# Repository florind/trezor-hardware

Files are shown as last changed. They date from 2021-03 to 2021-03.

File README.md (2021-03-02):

# Hardware design of Trezor

##
Using only 0603 components instead of 0402. Beware, the pushbuttons are also changed with https://www.mouser.de/ProductDetail/506-147873-2 (I have those).



https://trezor.io/

## Open Source Hardware

oshw

The content of this repo is dual licensed under the following licenses:
* [GNU Affero General Public License v3](COPYING)
* [CERN Open Hardware Licence Version 2 - Strongly Reciprocal](LICENSE)

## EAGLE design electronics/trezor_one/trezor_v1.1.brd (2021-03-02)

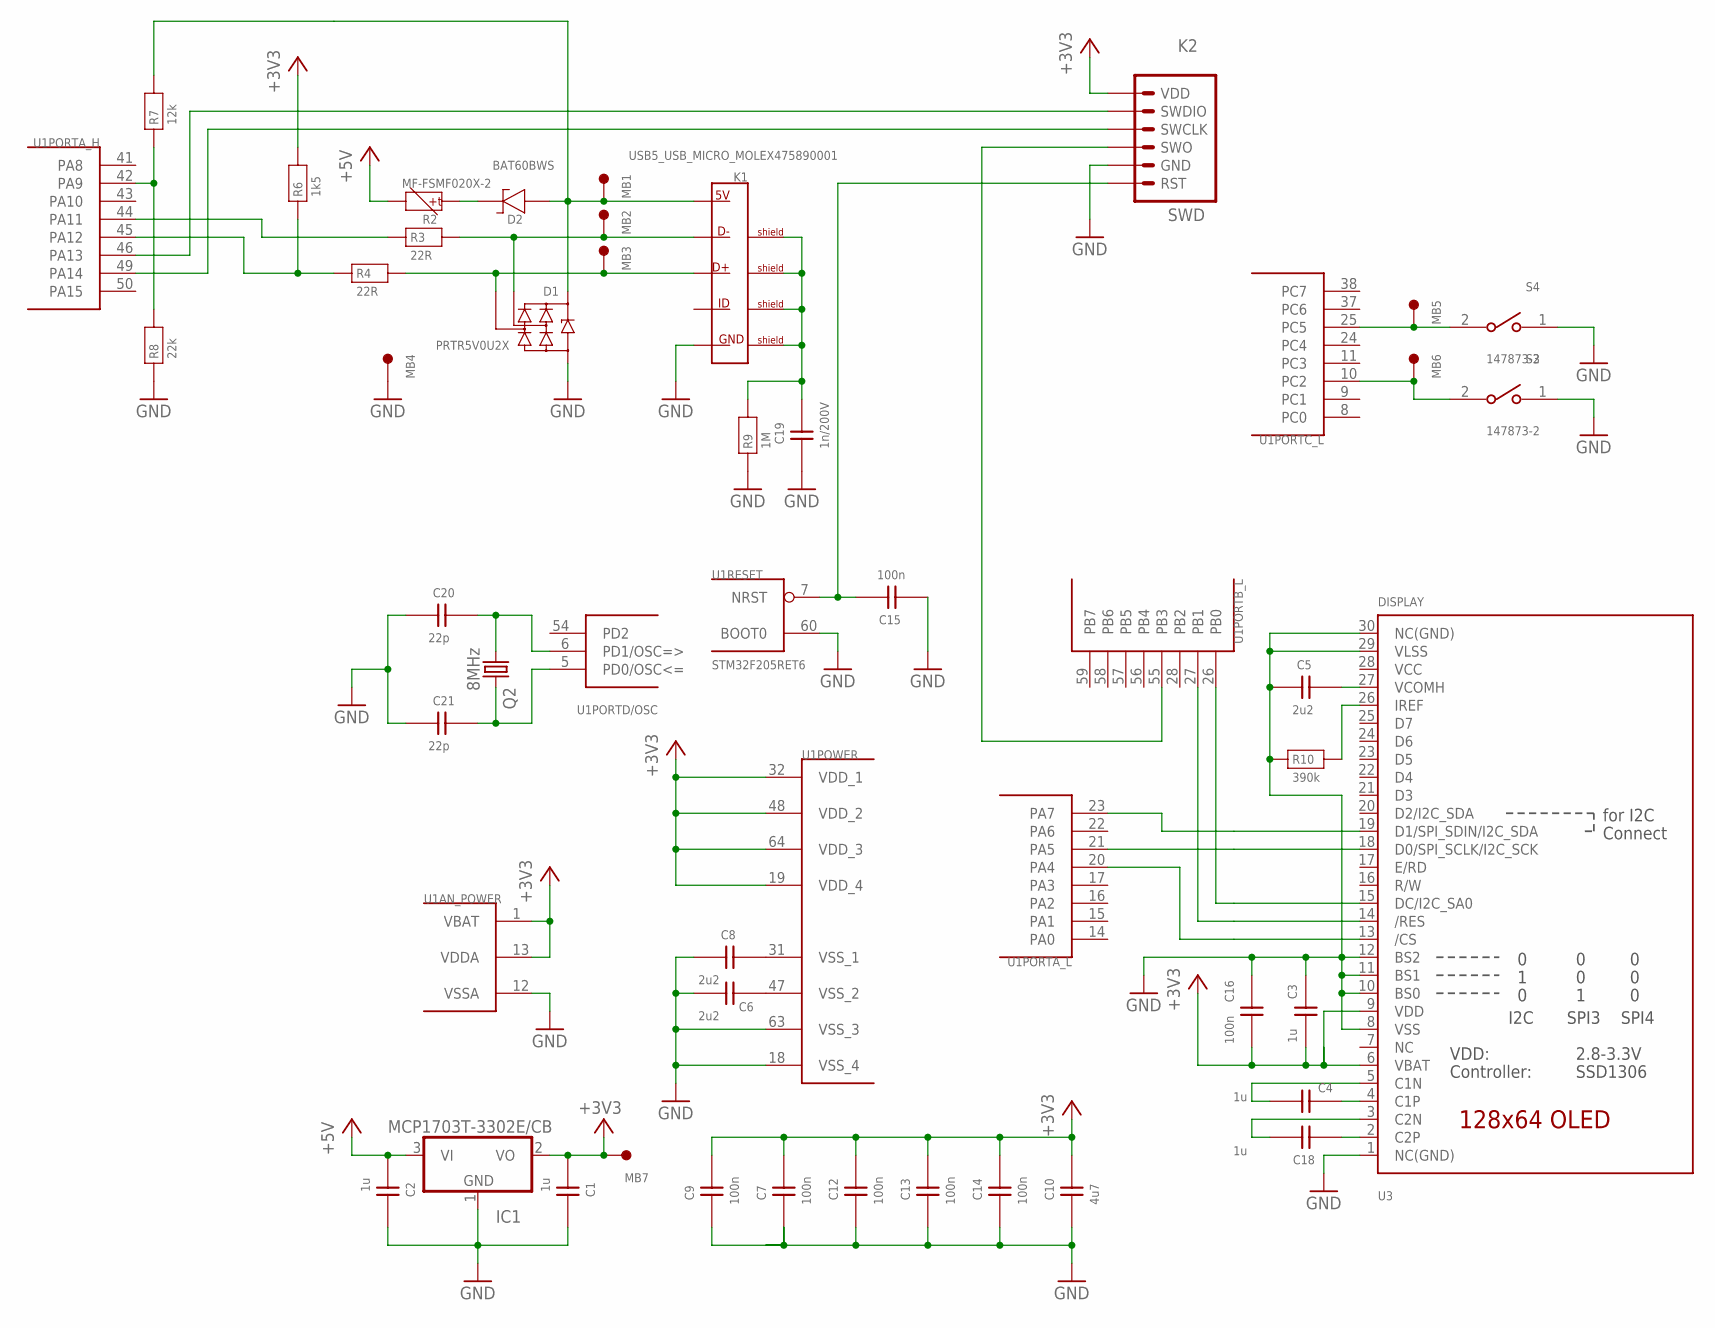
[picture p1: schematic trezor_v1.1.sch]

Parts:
C1, C2, C3, C4, C18: 1u; 0603
C5, C6, C8: 2u2; 0603
C7, C9, C12, C13, C14, C15, C16: 100n; 0603
C10: 4u7; 0603
C19: 1n/200V; 0603
C20, C21: 22p; 0603
D1: PRTR5V0U2X; SOT143B
D2: BAT60BWS; SOD323
IC1: MCP1703T-3302E/CB; SOT23
K1: USB5_USB_MICRO_MOLEX475890001; USB_MICRO-MOLEX475890001
K2: SWD
MB1, MB2, MB3, MB4, MB5, MB6, MB7: MB_1.50; MB1.5
Q2: 8MHz; CTS406
R2: MF-FSMF020X-2; 0603
R3, R4: 22R; 0603
R6: 1k5; 0603
R7: 12k; 0603
R8: 22k; 0603
R9: 1M; 0603
R10: 390k; 0603
S3, S4: 147873-2; SW_147873-2
U1: STM32F205RET6; TQFP64
U3: DISPLAY; UG-2864HSWEG01_0.96IN_WRAPAROUND

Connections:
+3V3: C1.1, C3.1, C7.2, C9.2, C10.2, C12.2, C13.2, C14.2, C16.1, IC1.2 (VO), K2.6 (VDD), MB7.1, R6.2, U1.1 (VBAT), U1.13 (VDDA), U1.19 (VDD_4), U1.32 (VDD_1), U1.48 (VDD_2), U1.64 (VDD_3), U3.6 (VBAT), U3.9 (VDD)
+5V: C2.1, IC1.3 (VI), R2.2
GND: C1.2, C2.2, C3.2, C5.1, C6.1, C7.1, C8.1, C9.1, C10.1, C12.1, C13.1, C14.1, C15.1, C16.2, C19.1, C20.1, C21.1, D1.1 (GND), IC1.1 (GND), K1.5 (5_GND), K2.2 (GND), MB4.1, R8.1, R9.1, R10.1, S3.1, S4.1, U1.12 (VSSA), U1.18 (VSS_4), U1.60 (BOOT0), U1.63 (VSS_3), U3.1 (NC(GND)), U3.8 (VSS), U3.10 (BS0), U3.11 (BS1), U3.12 (BS2), U3.29 (VLSS), U3.30 (NC(GND))
unnamed: U1.23 (PA7), U3.19 (D1/SPI_SDIN/I2C_SDA)
unnamed: C15.2, K2.1 (RST), U1.7 (NRST)
unnamed: U1.26 (PB0), U3.15 (DC/I2C_SA0)
unnamed: C8.2, U1.31 (VSS_1)
unnamed: U1.21 (PA5), U3.18 (D0/SPI_SCLK/I2C_SCK)
unnamed: C5.2, U3.27 (VCOMH)
unnamed: U1.27 (PB1), U3.14 (/RES)
unnamed: C6.2, U1.47 (VSS_2)
unnamed: R10.2, U3.26 (IREF)
unnamed: C18.1, U3.2 (C2P)
unnamed: C4.1, U3.4 (C1P)
unnamed: C18.2, U3.3 (C2N)
unnamed: C4.2, U3.5 (C1N)
unnamed: K2.3 (SWO), U1.55 (PB3)
unnamed: K2.5 (SWDIO), U1.46 (PA13)
unnamed: U1.20 (PA4), U3.13 (/CS)
unnamed: K2.4 (SWCLK), U1.49 (PA14)
unnamed: R3.1, U1.44 (PA11)
unnamed: MB5.1, S4.2, U1.25 (PC5)
unnamed: MB6.1, S3.2, U1.10 (PC2)
unnamed: D1.4 (VCC), D2.A (1), K1.1 (1_5V), MB1.1, R7.2
unnamed: D2.K (2), R2.1
unnamed: D1.2 (I/O1), K1.2 (2_D-), MB2.1, R3.2
unnamed: D1.3 (I/O2), K1.3 (3_D+), MB3.1, R4.2
unnamed: C19.2, K1.S1_BOT (SHIELD_1), K1.S1_TOP (SHIELD_1), K1.S2_BOT (SHIELD_2), K1.S2_TOP (SHIELD_2), K1.S3_BOT (SHIELD_3), K1.S3_TOP (SHIELD_3), K1.S4_BOT (SHIELD_4), K1.S4_TOP (SHIELD_4), K1.SA (SHIELD_1), K1.SB (SHIELD_2), R9.2
unnamed: R7.1, R8.2, U1.42 (PA9)
USB_D_P: R4.1, R6.1, U1.45 (PA12)
VCC: U3.28 (VCC)
XTAL1: C20.2, Q2.1, U1.6 (PD1/OSC=>)
XTAL2: C21.2, Q2.3 (2), U1.5 (PD0/OSC<=)

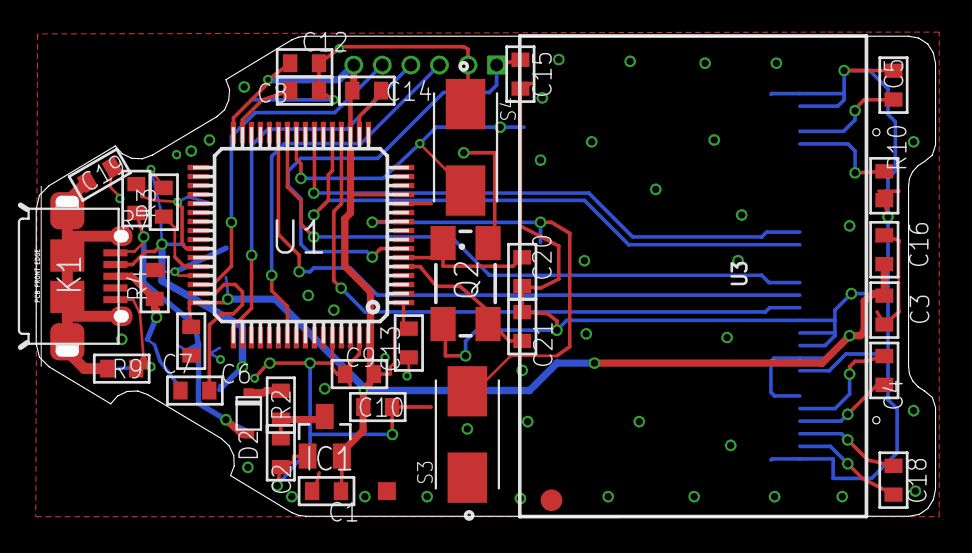
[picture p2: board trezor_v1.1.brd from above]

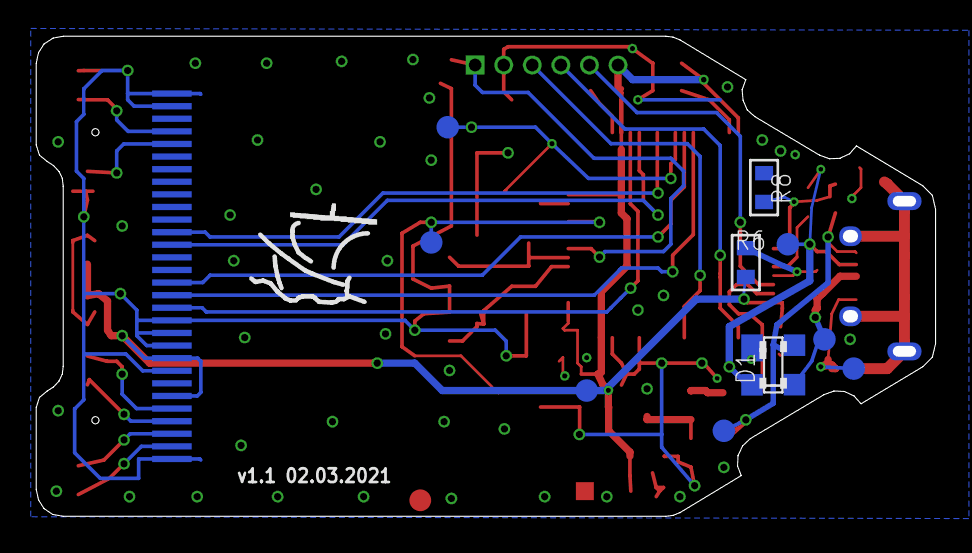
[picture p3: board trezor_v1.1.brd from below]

Board: 2 copper layers, 50.0 x 26.7 mm, 47 parts (10 on the bottom side), 32 nets.

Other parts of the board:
U$1: NEWSPLORE_LOGO_BPLACE_MID
U$3: BADMARK
U$4: CENTR

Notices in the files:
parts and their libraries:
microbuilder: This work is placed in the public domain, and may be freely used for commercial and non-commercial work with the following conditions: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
